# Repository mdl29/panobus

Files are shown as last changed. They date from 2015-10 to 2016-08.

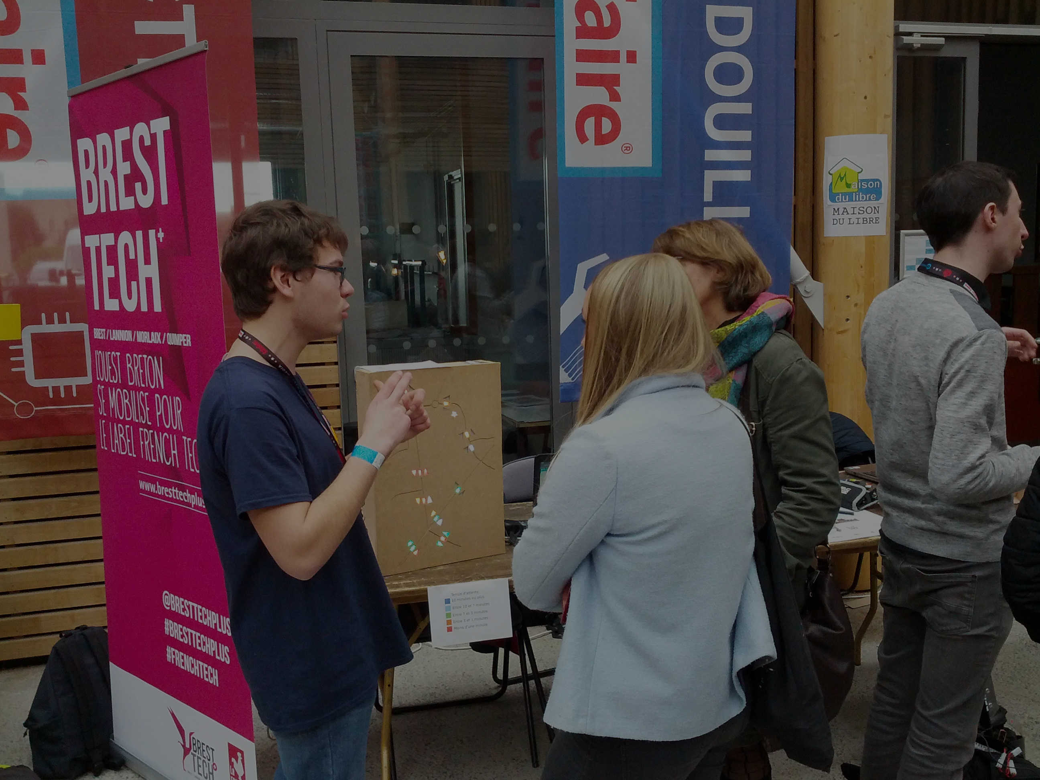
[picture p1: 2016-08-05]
website/img/bg1c-light.jpg

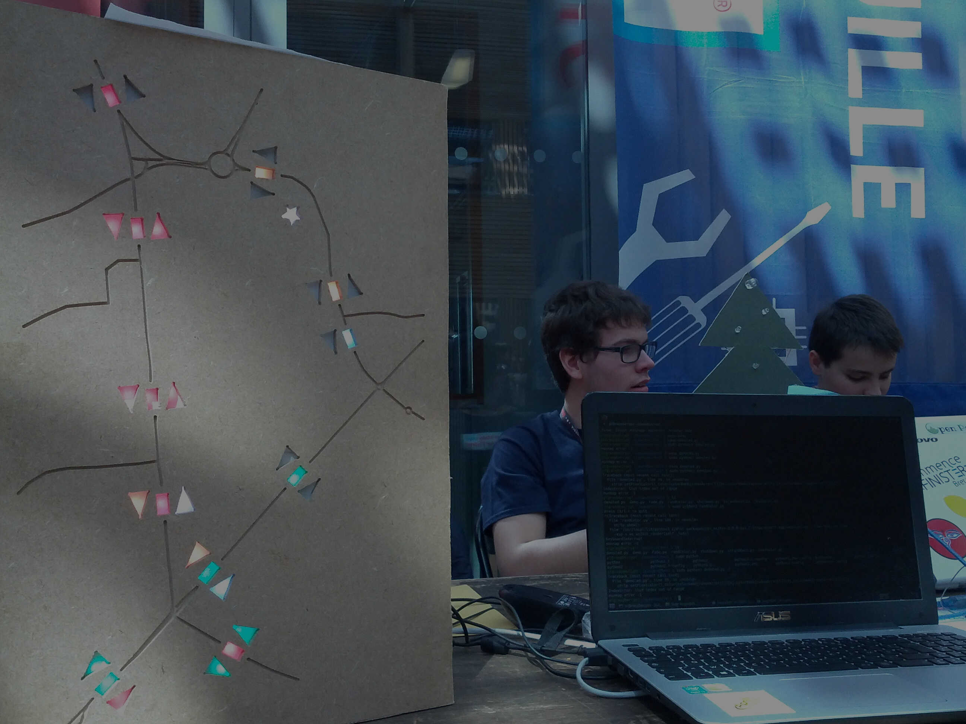
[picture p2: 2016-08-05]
website/img/bg2c-light.jpg

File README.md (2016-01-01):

# panobus
Panobus

Plus d'info sur <a href="https://wiki.mdl29.net/doku.php?id=lespetitshackers:bibus:panobus">le wiki de la Maison du Libre</a>

Fichier à éxecuter : main.py
/!\ Tous les logs sont dans bibus.log 

Pour que les informations soient transmises aux leds
```
./raspberryPi/main.py leds
```

Pour que les informations soient diffusées à l'écran
```
./raspberryPi/main.py logs
```

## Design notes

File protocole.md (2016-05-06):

###### PROTOCOLE ######
Voici l'amgorythme utilisé pour le panobus
#######################
##### Json #####
On utilise un JSON pour savoir quel arret "implementer" dans le script. Le json est de la forme suivante:

```
[
    {
        "name": "Liberte", //exemple
        "time2Go": 120,    //exemple
        "route": [
            {
                "name": "A",
                "dest": [
                    {
                        "name": "porte de plouzane",
                        "id": 0
                    },
                    {
                        "name": "porte de gouesnou",
                        "id": 1
                    },
                    {
                        "name": "porte de guipavas",
                        "id": 2
                    }
                ]
            }
        ]
    }
]
```

####################
##### Code #####
* la raspi récupère dans le Json :

    * Nombre de Station
    * l'ID de chaque arrêt
    * Le temps qu'on met pour aller à chaque station

* Toutes les n secondes la raspberryPy:

        * récupère via l'API le temps restant avant le passage des deux bus suivant pour chaque destination du panneau
        * calcule : "temps de passage - temps pour rejoindre" pour chaque temps
        * Si le temps obtenu est inférieur à 0min ET que le temps du bus suivant est inférieur au temps nécessaire pour rejoindre l'arrêt : ignore le bus qui arrive et traite les données du bus suivant
        * actualise la couleur des leds en fonction du résultat obtenu

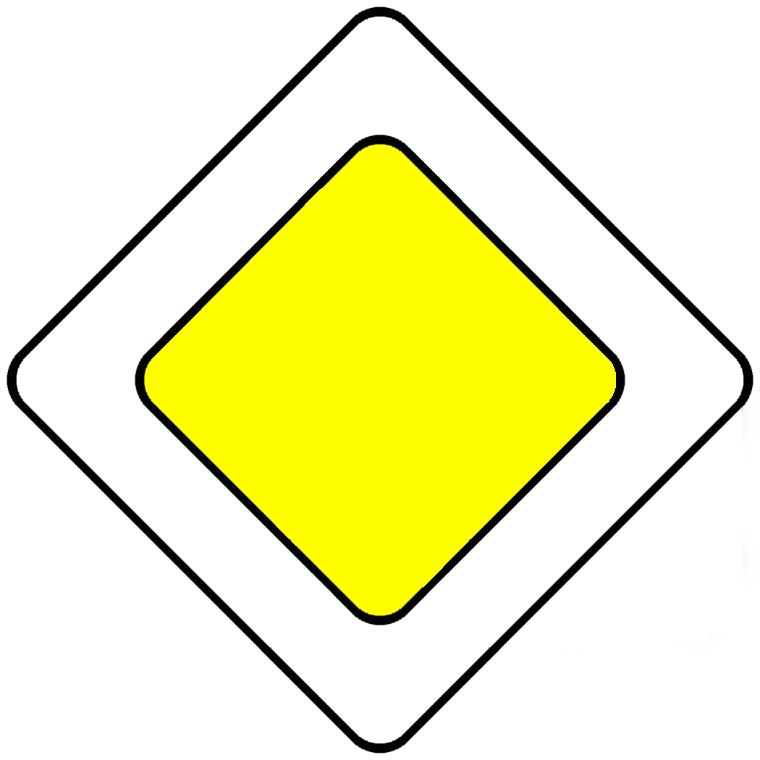
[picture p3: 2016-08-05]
website/img/panneau.png

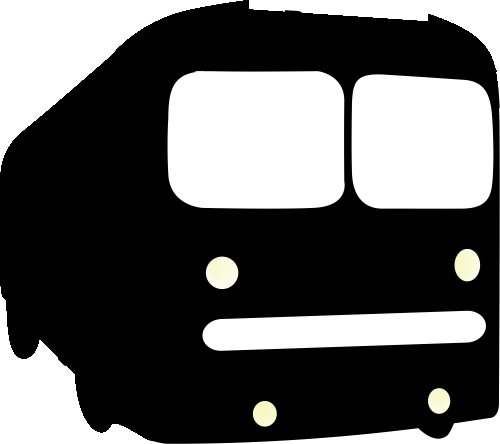
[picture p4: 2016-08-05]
website/img/bus.png

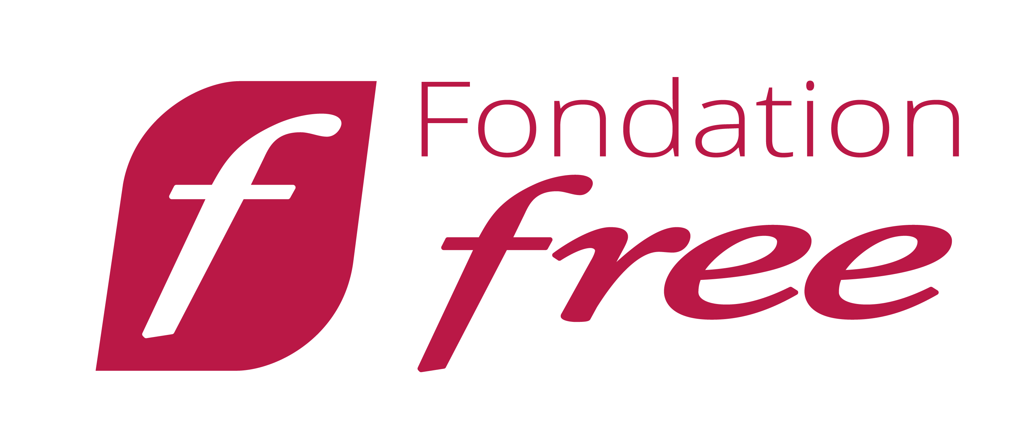
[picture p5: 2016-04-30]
website/img/FF.png

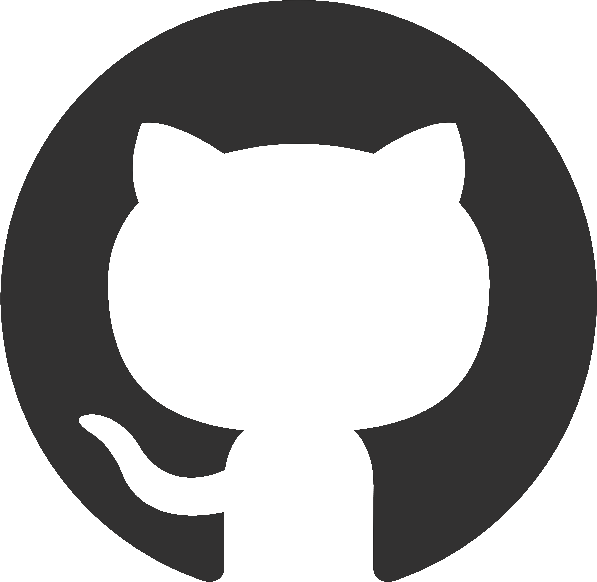
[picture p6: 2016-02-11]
website/img/git.png

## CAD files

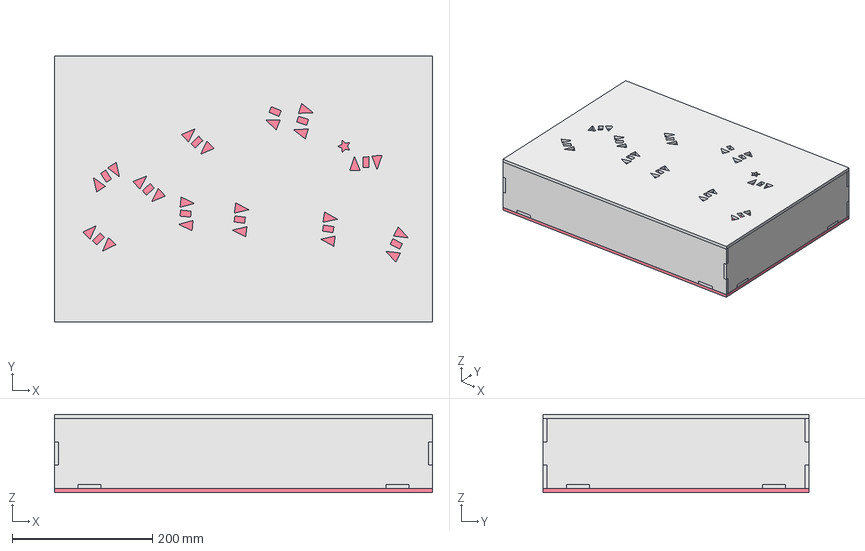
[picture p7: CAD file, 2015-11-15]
pano/Panneau bois/fond de carte Lycee/boite freecad/assemblage.fcstd
540.0 x 380.0 x 112.0 mm
coté 1_01
coté 2_01
coté 3_01
coté 4_01
coin_01
coin_02
coin_03
coin_04
face_arriere_01
face_avant_01

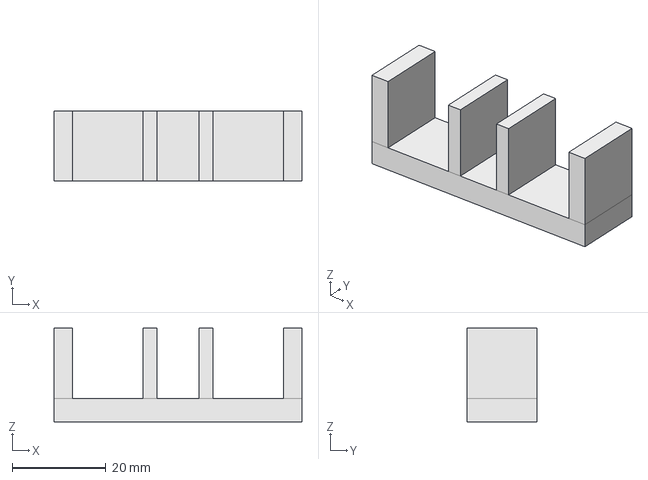
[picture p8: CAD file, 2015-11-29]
pano/Panneau bois/fond de carte Lycee/boite freecad/support led.fcstd
53.0 x 15.0 x 20.0 mm

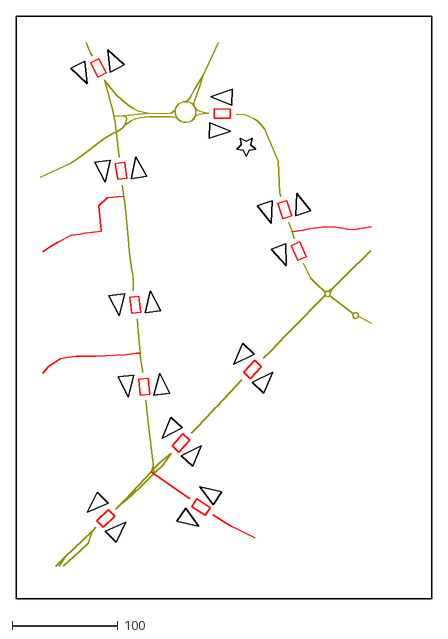
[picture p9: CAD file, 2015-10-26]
pano/Panneau bois/fond de carte Lycee/map.dxf
391.8 x 549.9

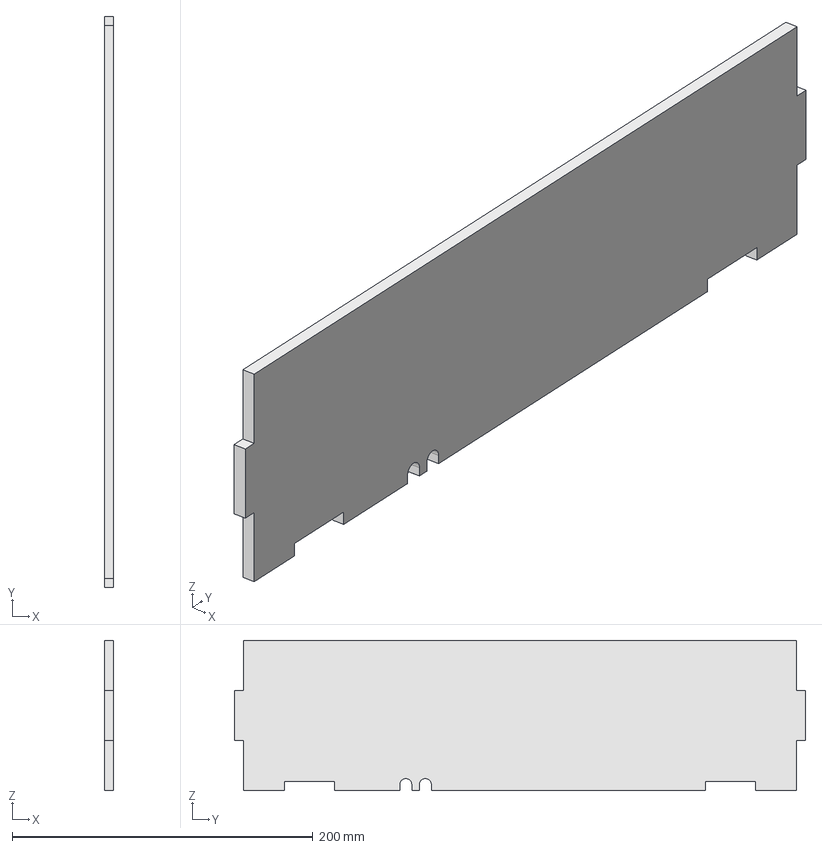
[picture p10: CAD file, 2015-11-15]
pano/Panneau bois/fond de carte Lycee/boite freecad/coté 2.fcstd
6.00 x 380.0 x 100.0 mm

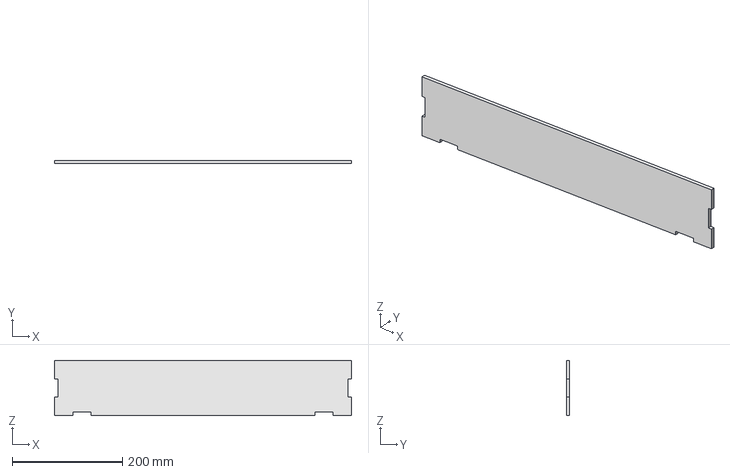
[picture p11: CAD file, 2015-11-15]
pano/Panneau bois/fond de carte Lycee/boite freecad/coté 1.fcstd
540.0 x 6.00 x 100.0 mm

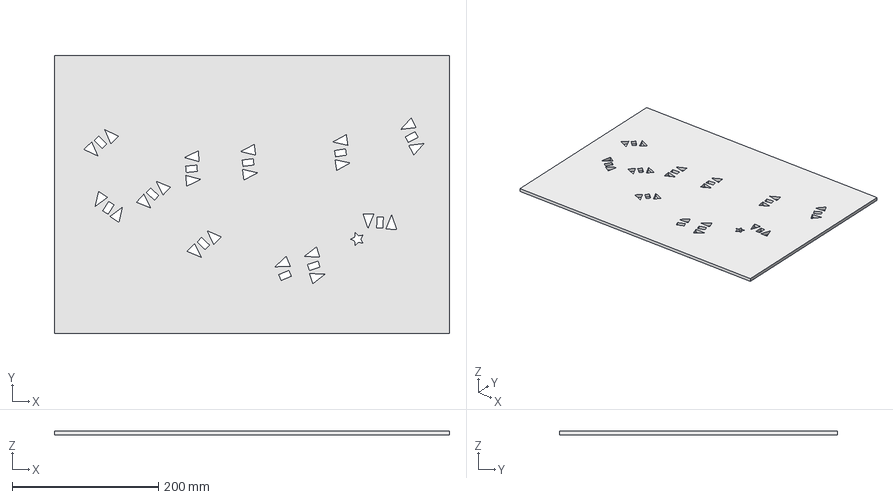
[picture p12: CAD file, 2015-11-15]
pano/Panneau bois/fond de carte Lycee/boite freecad/face avant.fcstd
540.0 x 380.0 x 6.00 mm

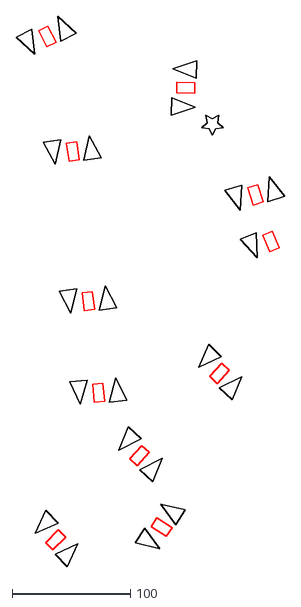
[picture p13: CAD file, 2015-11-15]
pano/Panneau bois/fond de carte Lycee/boite freecad/map.dxf
226.8 x 465.1

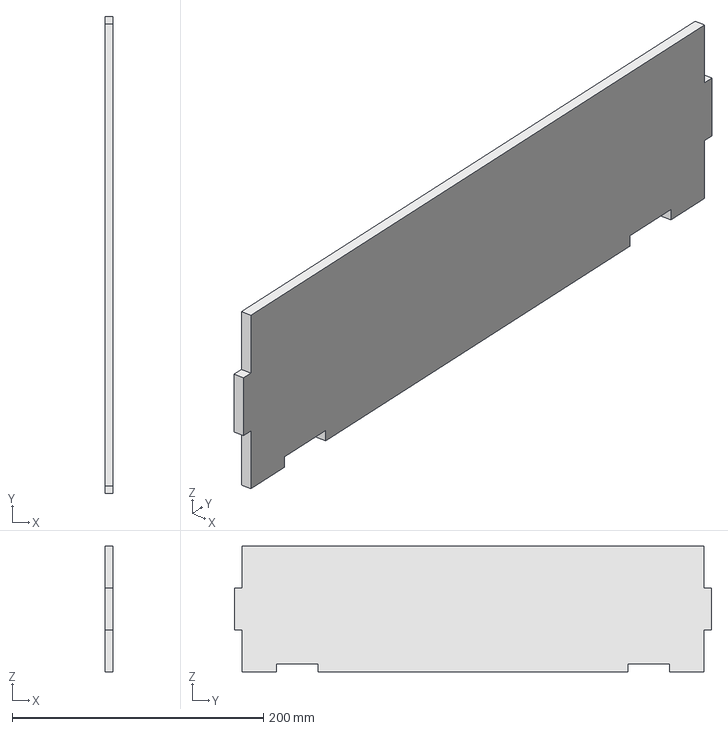
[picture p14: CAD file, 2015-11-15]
pano/Panneau bois/fond de carte Lycee/boite freecad/coté 4.fcstd
6.00 x 380.0 x 100.0 mm

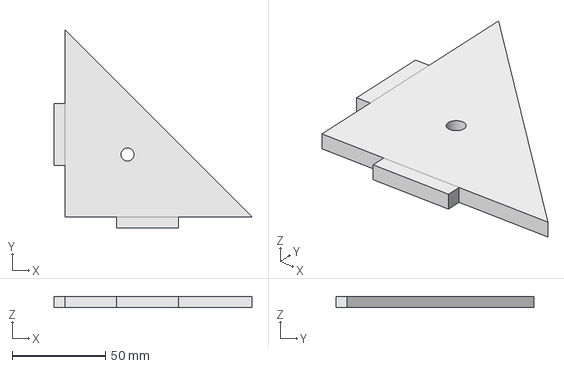
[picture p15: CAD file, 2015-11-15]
pano/Panneau bois/fond de carte Lycee/boite freecad/coin.fcstd
106.0 x 106.0 x 6.00 mm

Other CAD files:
pano/Panneau bois/fond de carte Lycee/boite freecad/coté 3.fcstd
pano/Panneau bois/fond de carte Lycee/boite freecad/face arriere.fcstd

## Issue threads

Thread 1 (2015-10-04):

Tests unitaires

naegi, 2015-10-04:
Fonctions à tester :
*  ~~getRemainingTimes~~
* ~~getStopNames~~
* ~~getRoutes~~
* ~~getDestinations~~
* ~~getRoutesStops~~

**Plus rien à tester pour le moment**

Boblecodeur, 2015-10-04:
Attention il s'agit de getDestinations et non pas de getdestinations

naegi, 2015-10-04:
Mettre à jour le test de getVersion (on est plus en bêta)

Closed 2016-02-10.

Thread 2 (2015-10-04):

erreur lors du lancement de ./maketest.sh

Boblecodeur, 2015-10-04:
Traceback (most recent call last):
  File "./bibus-test.py", line 3, in <module>
    import bibus
  File "../bibus.py", line 5
    def __init__(self,what:str):
                          ^
SyntaxError: invalid syntax

naegi, 2015-10-04:
C'est quoi ta version de python ?

naegi, 2015-10-04:
Il faut lancer python 3.x

HS-157, 2015-10-04:
C'est ça être sur un système obsolète qui utilise Python2.7 par défaut

Closed 2015-10-04.

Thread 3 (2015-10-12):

Erreur sur certains arrets

Boblecodeur, 2015-10-12:
Les arrets comportant des espaces comme "Porte de plouzané, Porte de gouesnou, Porte de guipavas, Port de commerce, etc..." ne sont pas suportés pour l'envoi des données dans l'url.

naegi, 2015-10-12:
Si tu peux corriger ça vite, moi je peux pas là Import urllib.parse (ou un truc dans le genre) 

Et pour chaque arg rajoute dans les format urllib.parse.urlencode

^^ merci d'avance 

------
Tristan Gouge

On Mon, Oct 12, 2015 at 8:07 PM, Boblecodeur <notifications@github.com>
wrote:

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

Benvii, 2015-10-12:
Je peux le faire demain soir (mardi soir) si c'est pas urgent. Vu trop tard pour le faire ce soir.

A+

naegi, 2015-10-13:
Tant que personne n'utilise le code c'est pas important pour le moment mais ça permet de vite clore l'issueBenjamin tant que t'es là je vais faire un peu de hors sujet mais faudrait faire un cour sur les tests (unitaires... Etc...) parce que je vois que Tristan ne sais pas vraiment comment ça fonctionne (il a pas mis d'assert dans ces tests par exemple) et j'ai de forte présomption pour que seul un ou deux sais ce que c'est et que moins encore les utilise -moi même, j'avoue, c'est le premier code où j'essaye de tester systématiquement, peut être mal qui sais 

------
Tristan Gouge

On Tue, Oct 13, 2015 at 12:13 AM, Benjamin BERNARD
<notifications@github.com> wrote:

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

Boblecodeur, 2015-10-13:
Je N'ai pas mis dassert car je n'ai pas fini j'ai chercher déjà comment
faire pour gérer les espaces

Le mar. 13 oct. 2015 08:06, naegi <notifications@github.com> a écrit :

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

Benvii, 2015-10-13:
C'est corrigé j'en ai profité pour refactorer un peu le code, quand je vois la structure des méthodes get* je me dit qu'il y a moyen de factoriser un peu plus ;)
Je vous laisse gérer le reste.

A+

Closed 2015-10-13.

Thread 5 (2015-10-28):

Remarque

tristanplouz, 2015-10-28:
Apres quelques tests avec le code arduino, je trouve que la frequence de rafraichissment n'est pas assez elevé. Le bus passe de EN APPROCHE à LOIN, c'est un peu dommage.
Il faudrait rafraichir toutes les 30s je pense.
Qu'en pensez vous?

naegi, 2015-10-28:
même avec un décompteur côté arduino ?

Le 28 octobre 2015 17:20, Boblecodeur <notifications@github.com> a écrit :

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

Boblecodeur, 2015-10-28:
Comment ça un decompteur? Si c'est faire décrémenté un compteur côté arduino, il vaut mieux réduire l'intervalle d'envoi

naegi, 2015-10-28:
Bah pendant que le main.py lance echo '["setUpdateInterval","n"]' >
/tmp/bibusPipe avec n le nbr de secondes

Le 28 octobre 2015 17:41, Boblecodeur <notifications@github.com> a écrit :

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

naegi, 2015-11-22:
Mettre le délai dans le json paraît correct pour toi ?

tristanplouz, 2015-11-22:
Bah on le laisse à 30secondes, je pense que cela suffit

Closed 2015-11-22.

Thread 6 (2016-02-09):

Neopixel sur pc

naegi, 2016-02-09:
Je propose de créer une sorte de library vide basé sur l'api de neopixel (au moins ce que l'on utilise) pour que l'on puisse tester le code de ledHandler et compagnie sur pc
Ajouter des tests et des infos de debuggages dans la lib est fortement envisageable je pense
Qu'en pensez vous ?

Benvii, 2016-02-09:
+1 et pourquoi pas en gros faudrait se baser sur "l'interface" de Adafruit_NeoPixel (qui n'est pas énorme : https://github.com/jgarff/rpi_ws281x/blob/master/python/neopixel.py ).
Mais c'est à mon sens trop complexe pour le relier à des tests unitaires ... sauf si de l'autre coté tu as aussi des jeux de données de test bibus en entrée :)
Donc se subtituer à l'API Bibus ce qui serait intéressant ça ouvrirait aussi la porte à d'autres API (La Star à Rennes ...) ça nécessite de revoir le code et réfléchir à quelque chose d'ultra modulable (regarder d'autres API).

naegi, 2016-02-09:
J'y avais pensé, mais j'avais pensé à juste créer un wrapper avec une api
«de base» (d'après ce que l'on utilise) qui sera redéfinie pour chaque api
que l'on ajoute le problème c'est comment passer d'une api à l'autre sans
avoir à modifier le code (j'avais pensé à un = __import__(api name) mais je
trouve ça moche)

Le mar. 9 févr. 2016 12:42 PM, Benjamin BERNARD <notifications@github.com>
a écrit :

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
--

------
Gouge Tristan

tristanplouz, 2016-02-10:
Pour développer le projet il faudrait qu'il soit construit en 3 partie:

- Une partie API avec la gestion des API de Bibus, de la STAR, de KSMA,etc

- Une partie qui traite les infos indépendantes des API et de l'affichage

- Une partie qui gère l'affichage sur les LEDs ou sur un écran

Avec cette structure je pense que le projet sera entièrement modulable et ensuite plus simple à modifier

naegi, 2016-02-10:
Comme on fait actuellemen j'ai envie de dire
L'issue part en HS j'ouvre une autre

Closed 2016-02-10.

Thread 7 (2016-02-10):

S'étendre à d'autres villes que Brest

naegi, 2016-02-10:
Reprise des message de #6
Benvi :
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

Moi :
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

Tristanplouz:
>Pour développer le projet il faudrait qu'il soit construit en 3 partie:

>- Une partie API avec la gestion des API de Bibus, de la STAR, de KSMA,etc

>- Une partie qui traite les infos indépendantes des API et de l'affichage

>- Une partie qui gère l'affichage sur les LEDs ou sur un écran

>Avec cette structure je pense que le projet sera entièrement modulable et ensuite plus simple à modifier

Benvii, 2016-02-11:
@naegi tu auras dans tous les cas besoin de faire un import :) après tu peux utiliser un patron de conception genre Adapter, tu as une implem pour chaque API qui est potentiellement complètement différente tu défini une interface et tu adapte chaque implem pour chaque API.

naegi, 2016-02-11:
C'est ce à quoi  je pensais en parlant de créer un wrapper autour des api (faut vraiment que j'apprenne le nom de patrons de conception)

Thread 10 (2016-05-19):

Décalage

LeonisCuriosity, 2016-05-19:
lorsqu'on arrive sur la dernier diapo, il se crée un espace en bas qui décale toutes les pages de (20px et quelques) vers le haut.
Cet écart n'est résorbé que lorsqu'on bidouille la hauteur de la fenêtre ou qu'on se met sur la première page.

naegi, 2016-05-20:
Corrigé par commit   0da4df4  ? Chez moi oui, je te laisse finir de tester

Closed 2016-05-21.

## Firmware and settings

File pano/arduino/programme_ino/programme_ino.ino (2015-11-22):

/*
Code du Projet Panobus
 Pour un pano implenté dans le Lycée avec 21 arrets referencés
 */

#include <Adafruit_NeoPixel.h>

#define arret_size 21


//DEFINITIONS DES COULEURS A REVOIR SUR LES VRAIES LEDS
#define R5 220//Original 220
#define G5 108//Original 108
#define B5 2//Original 2

#define R7 190//Original 190
#define G7 30//Original 84
#define B7 32//Original 86

#define R8 0//Original 0
#define G8 230//Original 119
#define B8 30//Original 48

#define R12 91//Original 91
#define G12 190//Original 171
#define B12 100//Original 154

#define R_LA 255
#define G_LA 0
#define B_LA 0

#define R_PRET 255
#define G_PRET 50
#define B_PRET 0

#define R_PROCHE 20
#define G_PROCHE 250
#define B_PROCHE 20

#define R_APPROCHE 0
#define G_APPROCHE 200
#define B_APPROCHE 255

#define R_LOIN 0
#define G_LOIN 0
#define B_LOIN 255

Adafruit_NeoPixel tempsAttenteLeds = Adafruit_NeoPixel(21, 6, NEO_GRB + NEO_KHZ800);
Adafruit_NeoPixel arretLeds = Adafruit_NeoPixel(12, 7, NEO_GRB + NEO_KHZ800);


int arret[arret_size];
int incomming=0;
int increment = 0 ;
long lastUpdate;
int compteurTest;

void setup(){
  Serial.begin(9600);

  tempsAttenteLeds.begin();
  arretLeds.begin();

  for(int i=0;i<3;i++){
    arretLeds.setPixelColor(i, arretLeds.Color(R8,G8,B8));
  }
  arretLeds.setPixelColor(3, arretLeds.Color(R12,G12,B12));
  arretLeds.setPixelColor(4, arretLeds.Color(R5,G5,B5));
  arretLeds.setPixelColor(5, arretLeds.Color(R8,G8,B8));
  arretLeds.setPixelColor(6, arretLeds.Color(255,255,255));
  for(int i=7;i<12;i++){
    arretLeds.setPixelColor(i, arretLeds.Color(R7,G7,B7));
  }
}

void loop(){
  if(millis()-lastUpdate>1&&compteurTest<5){
    testLeds();
    Serial.println(compteurTest);
  }
  else if(millis()-lastUpdate>600000 && compteurTest>=5){
    Serial.println(compteurTest);
    for(int i = 0;i<22;i++){
        tempsAttenteLeds.setPixelColor(i, tempsAttenteLeds.Color(0,0,0));
    }
    for(int i = 0;i<12;i++){
        arretLeds.setPixelColor(i, arretLeds.Color(0,0,0));
    }
  }
  getData();
}

void getData(){

  if(Serial.available()>0){
    incomming = Serial.read();
    /*Serial.print("increment: ");
     Serial.print(increment);
     Serial.print(" incomming : ");
     Serial.println(incomming);*/
    if(increment == 0 && incomming != arret_size){
      Serial.print("Erreur ");
      Serial.print(arret_size);
      Serial.print(" ");
      Serial.println(incomming);
      increment=0;
    }
    else if(increment == 0 && incomming == arret_size){
      Serial.println("No erreur");
      digitalWrite(13,HIGH);
      lastUpdate=millis();
    }
    arret[increment-1]=incomming-10;
    increment++;
    if(increment-1 == arret_size){
      Serial.println("FIN DE RECEPTION");
      digitalWrite(13,LOW);
      printData();
      increment = 0 ;
    }
  }
}

void printData(){
  for( int i = 0; i <arret_size;i++){
    if(actual==i||actual+2==i){
      Serial.print("*");
    }
    if(arret[i]>240){
      Serial.println("BUS LOIN");
      tempsAttenteLeds.setPixelColor(i, tempsAttenteLeds.Color(R_LOIN,G_LOIN,B_LOIN));
    }
    else if(arret[i]>150){
      Serial.println("BUS EN APPROCHE");
      tempsAttenteLeds.setPixelColor(i, tempsAttenteLeds.Color(R_APPROCHE,G_APPROCHE,B_APPROCHE));
    }
    else if(arret[i]>100){
      Serial.println("BUS PROCHE");
      tempsAttenteLeds.setPixelColor(i, tempsAttenteLeds.Color(R_PROCHE,G_PROCHE,B_PROCHE));
    }
    else if(arret[i]>50){
      Serial.println("BUS PRET");
      tempsAttenteLeds.setPixelColor(i, tempsAttenteLeds.Color(R_PRET,G_PRET,B_PRET));
    }
    else if(arret[i]<5){
      Serial.println("BUS LA");
      tempsAttenteLeds.setPixelColor(i, tempsAttenteLeds.Color(R_LA,G_LA,B_LA));
    }
  }

}

void testColor(int r,int g, int b){
  analogWrite(11,r);
  analogWrite(10,g);
  analogWrite(9,b);

}

void testLeds(){
  Serial.println("No more data leds test mode");
  for(int i = 0;i<21;i++){
    for(int j = 0;j<255;j++){
      for(int k =0; k <255;k++){
        for(int l =0; l <255;l++){
          tempsAttenteLeds.setPixelColor(i, tempsAttenteLeds.Color(j,k,l));
          delay(10);
        }
      }
    }
  }
  for(int i = 21;i>0;i--){
    for(int j = 255;j>=0;j--){
      for(int k =255; k>=0;k--){
        for(int l =255; l>=0;l--){
          tempsAttenteLeds.setPixelColor(i, tempsAttenteLeds.Color(j,k,l));
          delay(10);
        }
      }
    }
  }
  lastUpdate=millis();
  compteurTest++;

}

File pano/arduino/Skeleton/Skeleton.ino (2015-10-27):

#include <avr/sleep.h> //for die()

#define REQ_LENGTH 21 //require length, don't set it if you want a changing value or I don't know why 

void die (); //put arduino to sleep mode, better than exit who just put arduino in a while(1);

void setup() {
    Serial.begin(9600);
}

void loop() {

    byte length; //Should be a byte
    byte* buf = NULL;
    byte i = 0; //index counter, ugly, but I can't do otherwise, 

    // /!\ Should fail if the arduino is not connected BEFORE the rpi
    while(true){ // Block until end of data
        //receive data
        if (Serial.available() > 0) { //if receinving data

            if(!buf){ //if receiving new data block, set up correct stuff
                length = Serial.read(); //length of receiving data

#ifdef REQ_LENGTH
                if(length != REQ_LENGTH){
                    die(); //If occur, the is a problem, (bad rpi-side ?)
                }
#endif

                buf = (byte*) malloc(length);
                continue;
            }

            buf[i++] = Serial.read();

            if(i == length)
                break;
        }
    }

    //process data
    for(i = 0; i < length; i++){
        Serial.print(buf[i]);
        Serial.print('\n');
        //PROCESS DATA AND SEND TO LEDS
    }

    free(buf);
}

void die(){
    set_sleep_mode( SLEEP_MODE_PWR_DOWN  );
    while(true){
        sleep_enable();
        cli();
        sleep_cpu();
    }
}

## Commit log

2015-09-16 Reorganisation code;ajout 1er test /!\ Faut continuer à mettre des tests
2015-10-04 Modification de la version de python et ajout d'un log dans le test
2015-10-09 Ajout de Tests / Correction de bugs
    [bibus.py, main.py]
2015-10-09 Ajout de la partie materiel
    [map.dxf]
2015-10-12 Ajout de certaines fonctions plus ou moins utiles et des tests associés
2015-10-13 modification legere de la decoupe
    [map.dxf]
2015-10-13 Ajout d'un fichier pour décrire le protocole de communication Pi-Arduino (faut être clair pour tout le monde
2015-10-16 Modification de la forme du JSON et ajout de fonctionnalité La ligne 3 ne GET pas correctement les passages car son arret est "liberté place" et non "liberté"
    [main.py]
2015-10-17 ajout de 2 lignes protocolaires
2015-10-17 get et traite les infos des bus
2015-10-21 Modification de la partie materiel Ajout du JSON du lycée
2015-10-21 Ajout du JSON dans le script python des fois sa marche defois ca amrche pas
2015-10-24 Envoie 255 si pas de données
2015-10-26 Modification des maps
    [map.dxf]
2015-10-26 Ajout du support de la liaison série
2015-10-26 Augmente la rapidité du quit
2015-10-26 Ajout d'un exemple pour la gestion côté Arduino
2015-10-27 ajout de la compatibilité pour tout Python > 3
2015-10-27 reduction du niveau de log (maintenant uniquement les warnings et plus sont affichés)
2015-10-27 Changement de type pour les variables vers un type plus adapté
2015-10-28 Ajout de ma version du code arduino
2015-10-28 Ajout de test leds et de 'veille'
2015-11-12 Debut de realisation du boitier
    [arret.dxf, cote grand.fcstd, cote petit.fcstd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]
2015-11-13 Modification du boitier ajout des pieces coins, mais pas encore dans l'assemblage
    [coin.fcstd, cote grand.fcstd, cote petit.fcstd]
2015-11-15 Amelioration du model 3D du boitier
    [arret.dxf, assemblage.fcstd, coin.fcstd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]
2015-11-15 Ajout esthetique sur le boitier
    [assemblage.fcstd, face avant.fcstd, map.dxf]
2015-11-15 Ajout de trou pour les cables
    [assemblage.fcstd, coté 1.fcstd, coté 2.fcstd]
2015-11-22 Debut d'integration de la librairi NeoPix en RaspBerryPi
2015-11-25 ajout du support v1 pour les modules leds
    [support led.fcstd]
2015-11-29 MAJ du support des leds
    [support led.fcstd]
2015-12-13 Communication serie retiree, implementation entiere de NeoPixel RPI2
2015-12-13 Correction de bug
2015-12-13 Modification pour que cela fonctionne
2015-12-13 Correction de bugs
2015-12-13 Entierement fonctionnel sur la raspberry Pi 2 /!\Il faut le module rpi_ws281x pour rpi2
2015-12-13 add a choice to communicate throught print or leds
2015-12-16 Modification de la facon de selectionner le mod, mtn en argument du script
2015-12-19 restructuration des fichiers
    [assemblage.fcstd, coin.fcstd, coté 1.fcstd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]
2015-12-19 Debut de la structure du site web
2016-01-01 HAPPY NEW year : ma résolution -> respecter la PEP 8 :) (environ 900 lignes de code changées)
2016-01-01 correction du merge raté
    [bibus.py, ledHandler.py, main.py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]
2016-01-13 Modification de la methode d'atribution des couleurs aux leds centrales
2016-01-30 Amélioration de la réactivité du programme
2016-02-04 Comprehension de pourquoi on avait beaucoup trop d'erreur (pas bibus My bad) regarder pour ligne 7 dest hopital tromeur et ligne 8 plougastel
2016-02-09 Fin de la mise en place du style
2016-02-09 Ajout de leaflet
2016-02-11 Mise en place d'un systeme simple d'ajout de pano
2016-02-15 Changement du site
    [generator_config.txt]
2016-04-30 Site web
    [generator_config.txt]
2016-05-03 recommence css depuis 0. Création du menu et de la première page
    [generator_config.txt]
2016-05-05 supression des images superflus
2016-05-05 utilisation de flex pour centrer les diapos
2016-05-06 Ajout de l'article de le monde
2016-05-21 site portrait plus ou moins ok sur tous les points
2016-07-07 correct bug on no more data
    [memorize.py]
2016-08-05 ajout de video
2016-08-08 modification de l'integration d'une video
